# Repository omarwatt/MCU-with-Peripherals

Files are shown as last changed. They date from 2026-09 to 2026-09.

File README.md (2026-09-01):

# RISC-V MCU with Memory-Mapped Peripherals

## Project Overview

An FPGA microcontroller project integrating a 32-bit RISC-V-style processor with GPIO, a timer, UART, and interrupt handling. The work covers processor–peripheral integration, memory-mapped control, interrupt-driven firmware, simulation, and on-board verification using Signal Tap.

## Main Features

- Separate 8 KiB instruction and 8 KiB data memories.
- GPIO for eight switches, eight LEDs, and six seven-segment displays.
- Timer with selectable clock division, compare events, PWM, and edge capture.
- UART transmit/receive registers, status flags, and configurable parity and baud selection.
- Prioritized interrupts from UART, timer, and external keys.
- Hardware multiplication and a multicycle divider, with implementation restrictions described below.

## Architecture

`MCU.vhd` connects the processor, memories, address decoding, and peripherals. The processor uses a single-cycle datapath with multicycle sequences for division and interrupt entry. `MCU_top.vhd` provides the board-facing wrapper.

Interrupt handling uses custom vectors, an active-low acknowledge, `gp[0]` as a software interrupt-enable bit, and `tp` to hold the return address. This is a project-specific mechanism rather than the standard RISC-V privileged interrupt architecture.

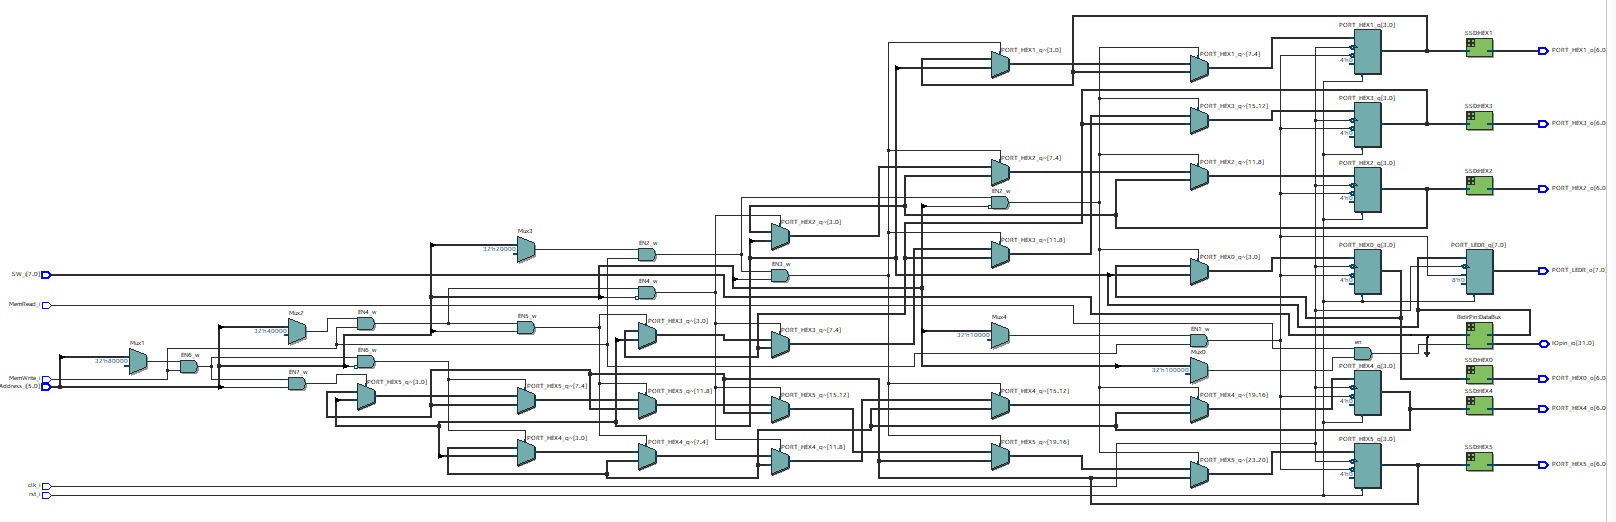
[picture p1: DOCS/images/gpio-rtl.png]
GPIO RTL structure

*Address decoding selects the GPIO registers and display outputs.*

## Tools and Technologies

VHDL, RISC-V assembly/C benchmarks, Intel Quartus Prime, ModelSim/Questa, Signal Tap Logic Analyzer, Intel `altsyncram` memories, and the DE10-Standard FPGA board.

## Simulation and Results

The archive contains block-level testbenches and an MCU testbench. UART and MCU tests include assertions; other tests also use directed stimulus and waveform inspection.

`DOC/pre.pdf` reports the following for the GPIO-and-interrupt configuration on Cyclone V `5CSXFC6D6F31C6`:

| Metric | Reported result |
| --- | ---: |
| ALMs | 2,017 |
| Registers | 1,743 |
| Memory bits | 131,072 |
| MCLK Fmax, slow 85°C corner | 29.09 MHz |

These are archived implementation results, not a newly reproduced build.

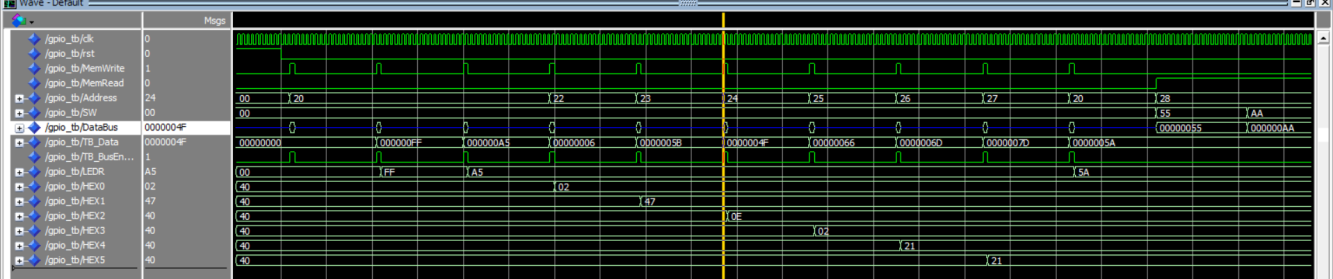
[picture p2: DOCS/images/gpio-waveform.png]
GPIO simulation

*MemWrite transactions update LEDR and HEX0–HEX5; MemRead returns switch patterns 0x55 and 0xAA on DataBus.*

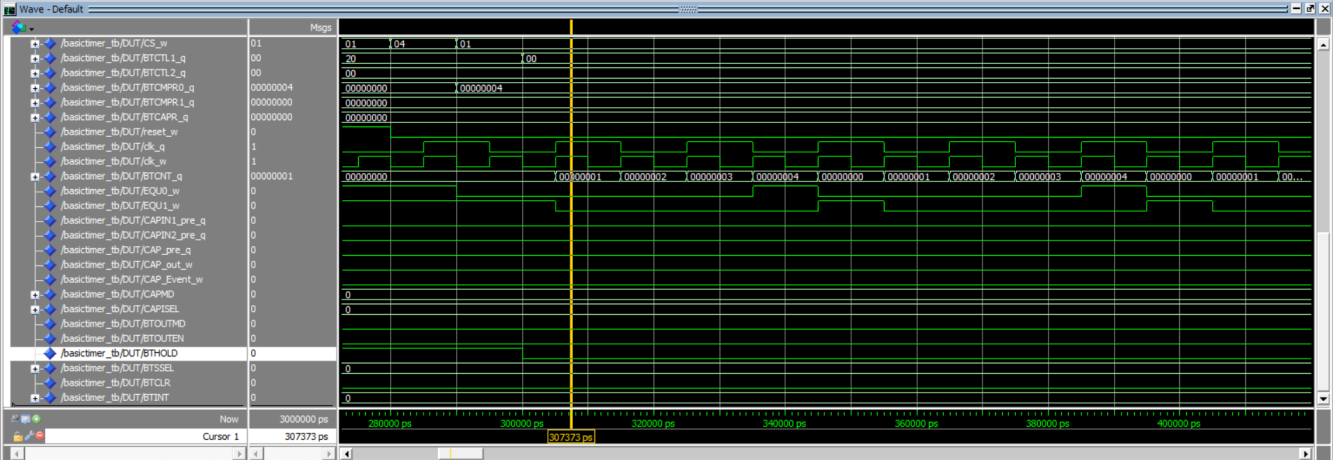
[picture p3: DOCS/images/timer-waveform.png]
Basic Timer simulation

*BTCNT_q counts to BTCMPR0 = 4 and reloads, while EQU0_w marks the compare event in this archived unit test.*

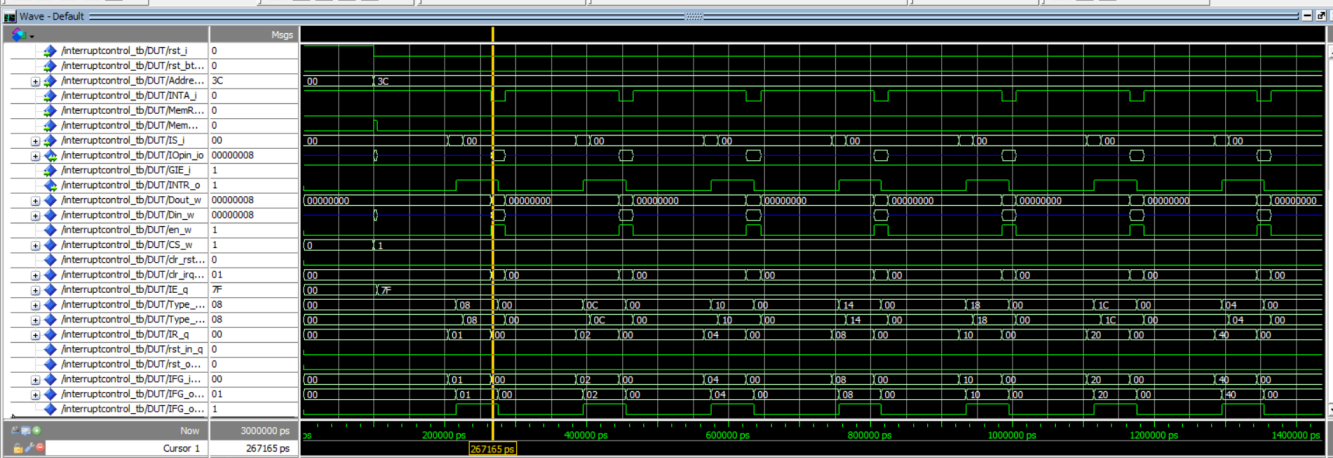
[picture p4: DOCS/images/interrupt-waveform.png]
Interrupt simulation

*IFG, TYPE, INTR, and active-low INTA show interrupt requests, vector selection, and acknowledgement.*

### On-Board Verification with Signal Tap

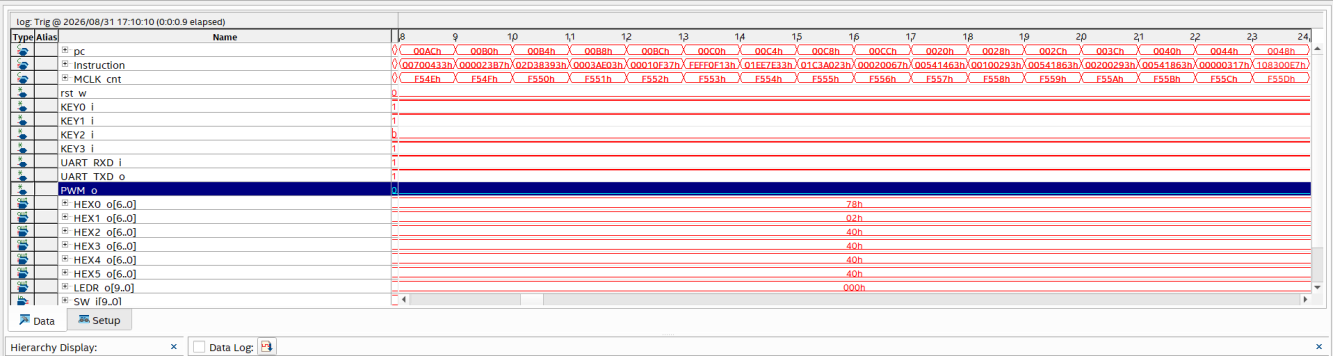
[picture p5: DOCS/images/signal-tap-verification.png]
On-board MCU Signal Tap capture

*The hardware capture shows the program counter, instruction words, advancing MCLK counter, and GPIO outputs during execution on the DE10-Standard board.*

The MCU was programmed onto the DE10-Standard board, and internal processor signals and peripheral outputs were captured using Signal Tap. The archived capture appears in `DOC/pre.pdf`, Figure 21 on page 14; `QUARTUS/stp1.stp` contains the Signal Tap session and recorded data.

- **Instruction execution:** the program counter advances through addresses including `0x00AC`–`0x00CC` and returns to the program loop, with instruction words captured alongside it.
- **Clock activity:** the MCLK counter advances from `0xF54E` to `0xF55D` in the displayed window, showing continued processor-clock activity.
- **Peripheral outputs:** `HEX0 = 0x78` and `HEX1 = 0x02` retain the programmed display values; `HEX2`–`HEX5` show `0x40`, and `LEDR` is zero. `PWM_o` is low and `UART_TXD` is high during this window.

The report compares the captured instruction flow and GPIO output states with the ModelSim benchmark run. This provides on-board evidence of processor execution and peripheral integration. The displayed idle UART and PWM levels do not independently verify serial transfers or PWM timing.

## Repository Structure

- `DUT/`: processor, peripherals, packages, memories, and board wrapper.
- `TB/`: block and MCU testbenches.
- `SIM/`: waveform configuration scripts.
- `Benchmark apps/`: example firmware and memory images.
- `QUARTUS/`: constraints, archived FPGA outputs, and the `stp1.stp` Signal Tap session.
- `DOC/`: project report.
- `docs/images/`: five selected design and results figures.

## How to Run

1. Configure a VHDL-2008 simulator with Intel's `altera_mf` simulation library.
2. Set `G_MODELSIM := 1` in `DUT/cond_compilation_package.vhd`.
3. Replace the absolute memory-image paths in `IFETCH.VHD` and `DMEMORY.VHD` with a matching instruction/data image pair.
4. Compile the packages, dependent DUT blocks, processor, MCU, and selected testbench in dependency order. Elaborate `tb_MCU` for system simulation.
5. Load the relevant waveform script under `SIM/` and run the testbench.

The waveform scripts do not compile the design. Match the MCU testbench's timer expectations to the selected firmware; its referenced fast-timer image is absent. Align the UART clock-frequency setting with the testbench clock before testing integrated serial communication.

To inspect the hardware verification, open `QUARTUS/stp1.stp` in Quartus Signal Tap and select the saved acquisition. For a new capture, connect the board through JTAG and use a matching FPGA programming file and Signal Tap configuration. Update the session's original absolute `.sof` path for your environment.

## Attribution

Course project by **Omar Wattad**, using the supplied course framework. The UART derives from **Jakub Cabal's uart-for-fpga**; retain its original copyright and MIT license notices alongside the course-code attribution.

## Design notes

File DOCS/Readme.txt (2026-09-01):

=====================================================================================================
FINAL PROJECT - RISCV-based MCU (Single-Cycle RV32IM Core + Memory-Mapped Peripherals + Interrupts)
Advanced CPU Architecture & Hardware Accelerators (361-1-4693) - Instructor: Hanan Ribo
Submitted by: Omar Wattad (207510819) , Fidaa Abo Aissa (324960996)
Target device: Intel Cyclone V  5CSXFC6D6F31C6  (DE10-Standard / DE-SoC board)
Tools: Quartus Prime 25.1std.0 | ModelSim | Signal-Tap | In-System Memory Content Editor (ISMCE) | RARS
=====================================================================================================

OVERVIEW
This project implements a complete RV32IM-based micro-controller (MCU) on an FPGA. The CPU is the
scalar single-cycle RV32IM core developed in LAB5, extended into a micro-controller by adding a
memory-mapped peripheral subsystem, an interrupt mechanism, a UART serial interface and a multicycle
unsigned division accelerator running in its own fast clock domain.

The design keeps the Harvard organisation of the core - separate ITCM (instruction) and DTCM (data)
tightly-coupled memories of 8 kB each. All peripherals are mapped into the Data Address Space above
the physical data memory (byte address 0x2000 and up) and share one bidirectional 32-bit Data BUS, so
the CPU accesses them with ordinary lw / sw instructions. The top level and the RV32IM core are both
structural. Push-button KEY0 is the system RESET (brings the PC to the first program instruction).

-----------------------------------------------------------------------------------------------------
CLOCKING
-----------------------------------------------------------------------------------------------------
baseclk 50 MHz -> Clock Tree / PLLs:
  MCLK    - core clock. Clocks the CPU, the bus, all peripherals and the MCLK counter.
  DIVCLK  - fast clock. Clocks the division accelerator only (32 DIVCLK cycles per 32-bit division).
  SMCLK   - peripheral clock source feeding the Basic Timer pre-scaler and the UART baud generator.
The MCLK and DIVCLK domains meet only through the Sync (CDC) block, so no combinational signal crosses
a clock boundary unregistered.

-----------------------------------------------------------------------------------------------------
CPU CORE SUB-MODULES  (RV32IM_CORE, structural)
-----------------------------------------------------------------------------------------------------

IFETCH (Ifetch:IFE)
Instruction-fetch stage. Holds the PC register and the PC+4 adder, contains the ITCM (8 kB, FPGA
embedded altsyncram), and selects the next PC through a mux choosing between PC+4, a branch/jump
target and - during an interrupt - the vector address supplied by the ISR sequence. Outputs the
fetched instruction and the current PC.

IDECODE (Idecode:ID)
Decode stage. Contains the RISC-V register file (32 x 32-bit, two read ports, one write port) and the
sign-extension / immediate-generation logic for I/S/B/U/J formats. Supplies read_data1 and read_data2
to EXECUTE and routes the write-back value into the destination register rd.

CONTROL (control:CTL)
Main control unit. Decodes opcode and funct fields into the datapath control signals: ALUOp, ALUSrc,
MULOp, DIVOp, Branch, Jal, Jalr, MemRead, MemWrite, MemtoReg, RegDst, RegWrite, UpperIm and WBSrc.
It also contains the multicycle ISR FSM (see "Interrupt service protocol" below) and handles PChold /
DIVbusy stalling while the division accelerator is busy.

EXECUTE (Execute:EXE)
Execute stage. Contains the ALU (add/sub, logic, shift, signed and unsigned comparison for branch
resolution), the 16-bit multiplier, branch-target / effective-address generation, and the result mux
that selects the value forwarded to memory / write-back (ALU result, multiplier result, divider
quotient/residue, memory data, PC+4 or the upper immediate).

16-BIT MULTIPLIER (mul)
Implements the mul instruction of the M-extension. mul rd, rs1, rs2 multiplies the lower 16-bit
half-words of rs1 and rs2 into a 32-bit product, built from four embedded 8-bit multipliers (DSP):
   P0 = A_low x B_low , P1 = A_low x B_high , P2 = A_high x B_low , P3 = A_high x B_high
   M  = P1 + P2 ,   RESULT = P0 + (M << 8) + (P3 << 16)
Purely combinational in the single-cycle core.

DMEMORY (dmemory:MEM)
Data-memory stage. Contains the DTCM (8 kB, FPGA embedded altsyncram) with the load/store interface,
clocked on not(clk) so a load can be fetched, decoded, address-computed and read in the same period.
It also hosts the bus interface logic: the address decoder that separates DTCM accesses from I/O
accesses, and the merge of the peripheral read data back onto the Data BUS.

MCLK COUNTER
A free-running cycle counter clocked by MCLK, cleared on reset; drives mclk_cnt_o.

-----------------------------------------------------------------------------------------------------
PERIPHERAL SUB-MODULES
-----------------------------------------------------------------------------------------------------

GPIO (GPIO_UNIT)
Eight memory-mapped GPIO peripherals: an optimized address decoder generates the chip-selects CS1..CSn
from Address<A4..A0>, MemWrite latches the Data BUS into the addressed port register, and MemRead with
the matching CS enables a tri-state driver (BidirPinDataBus) that returns the register onto the bus.
Each HEX port register passes through a 7-segment encoder (SSD.vhd) before leaving the block.
   PORT_LEDR 0x2000 (LEDR7-LEDR0, GPO)      PORT_HEX3 0x2009 (GPO)
   PORT_HEX0 0x2004 (GPO)                   PORT_HEX4 0x200C (GPO)
   PORT_HEX1 0x2005 (GPO)                   PORT_HEX5 0x200D (GPO)
   PORT_HEX2 0x2008 (GPO)                   PORT_SW   0x2010 (SW7-SW0, GPI)

PUSHBUTTONS (Pushbuttons / uart_debouncer)
PORT_PB (0x2014) exposes the three debounced pushbuttons KEY3-KEY1 as an input device. Each key is
debounced and edge-detected; the resulting pulse is an interrupt source (KEY1IFG / KEY2IFG / KEY3IFG)
towards the interrupt controller. KEY0 is NOT a peripheral - it is the system reset.

BASIC TIMER (BasicTimer)
32-bit up-mode timer with compare, PWM output and input capture.
   BTCTL1  0x201C  BTOUTMD | BTOUTEN | BTHOLD | BTSSEL | BTCLR | BTINT
   BTCTL2  0x201D  CAPMD | CAPISEL
   BTCMPR0 0x2020  compare/PWM value 0   (latched into BTCL0)
   BTCMPR1 0x2024  compare/PWM value 1   (latched into BTCL1)
   BTCAPR  0x2028  capture register
BTSSEL selects the counter clock from {SMCLK, SMCLK/2, SMCLK/4, SMCLK/8}. BTCNT counts up and is
cleared when it equals BTCL0, producing the periodic BTIFG interrupt (source selected by BTINT).
The Output Unit generates PWM_out in Output Mode0 (Set/Reset) or Mode1 (Reset/Set) from the BTCL0 /
BTCL1 comparisons. The capture path selects CAPIN1, CAPIN2, VCC or GND (CAPISEL), detects a rising or
falling edge (CAPMD) and latches BTCNT into BTCAPR on the event.

DIVISION ACCELERATOR (DIV + Sync)
Unsigned binary multicycle restoring divider, 32-bit. The dividend is held in a left-shift register,
the divisor in a register; each DIVCLK cycle the subtractor computes Y-X and a non-negative result
shifts a '1' into the quotient shift-register. Results (QUOTIENT, RESIDUE) are ready N=32 DIVCLK
cycles after the second operand is loaded; DIVBUSY stalls the CPU (PChold) meanwhile. Operands cross
from MCLK into DIVCLK through Sync.vhd - two cascaded DFF stages per operand (Ain, Bin) clocked by
DIVCLK, as required for a slow-to-fast clock-domain crossing, so no metastable value reaches the
divider datapath.

UART (uart, uart_tx, uart_rx, uart_parity, uart_debouncer)
USART peripheral in UART mode: 1 start bit, 8 data bits LSB-first, optional parity, 1 stop bit, with
independent transmit and receive shift registers and separate buffer registers.
   UCTL  0x2018  BUSY | OE | PE | FE | BAUDRATE | PEV | PENA | SWRST
   RXBF  0x2019  receive buffer  (reading it clears the receive error bits and RXIFG)
   TXBF  0x201A  transmit buffer (writing it clears TXIFG)
The baud-rate generator divides SMCLK to 9600 or 115200 (BAUDRATE bit). Status flags FE (framing),
PE (parity) and OE (overrun) are set by the receive control logic. RX and TX are independent
interrupt sources (RXIFG, TXIFG).

INTERRUPT CONTROLLER (InterruptControl)
   IE   0x202C  0 | 0 | KEY3IE  | KEY2IE  | KEY1IE  | BTIE  | TXIE  | RXIE
   IFG  0x202D  0 | 0 | KEY3IFG | KEY2IFG | KEY1IFG | BTIFG | TXIFG | RXIFG
   TYPE 0x202E  interrupt vector of the served source (read-only)
Each source drives a set-only flag flip-flop (clr_irq clears it). The flag is ANDed with its enable
bit, all masked requests are OR-ed together and gated by GIE to produce INTR towards the CPU. On INTA
the controller resolves the highest-priority pending source and drives its vector onto TYPE:
   00h RESET (NMI, highest) | 04h UART status error | 08h UART RX | 0Ch UART TX
   10h Basic Timer | 14h KEY1 | 18h KEY2 | 1Ch KEY3 (lowest)
BTIFG, RXIFG and TXIFG are cleared automatically when serviced (RXIFG also on RXBF read, TXIFG also on
TXBF write); the KEYiIFG flags are cleared by software.

SSD (SSD.vhd)
Combinational 4-bit-to-7-segment encoder instantiated once per HEX port inside the GPIO block.

-----------------------------------------------------------------------------------------------------
INTERRUPT SERVICE PROTOCOL (multicycle FSM inside CONTROL)
-----------------------------------------------------------------------------------------------------
The FSM is triggered by the falling edge of INTA, the cycle after the controller sets INTR = '1'. The
next PC at that moment is the interrupt return address.
Servicing (2-cycle latency):
  Cycle 1 : clear GIE (gp[0] = 0) in HW ; set INTA = '1' ; drive the TYPE content onto the Data BUS
            and capture it into a dedicated register (TYPE cannot go on the Address BUS - the CPU is
            the only bus master).
  Cycle 2 : if the pending source is synchronous, clear its flag (e.g. BTIFG) ; emulate load of the
            TYPE content followed by jalr to Mem[TYPE], with R[tp] = interrupt return address.
Return (1-cycle latency):
  As part of executing "jalr zero, 0(tp)" (reti), GIE is set again in HW.

-----------------------------------------------------------------------------------------------------
SYSTEM TOP ENTITY  (MCU_top.vhd, structural)
-----------------------------------------------------------------------------------------------------
Inputs : clk_i (50 MHz -> PLLs), KEY0 (system reset), KEY3-KEY1 (pushbutton peripheral / interrupts),
         SW9-SW0, CAPIN1, CAPIN2, UART_RXD
Outputs: LEDR9-LEDR0, HEX5-HEX0, PWM_o, UART_TXD
Submodules: RV32IM_CORE (CPU) , GPIO_UNIT , TIMER_UNIT , IC_UNIT , UART_UNIT , DIV + Sync ,
            PLL \G0:MCLK , PLL \G0:DIVCLK , MCLK counter.
Observation ports (Signal-Tap, removed from the final build through the generate parameter):
PC_o, Instruction_o, INTA_o, GIE_o, INTR_o, MemRead_ctrl_o, MemWrite_ctrl_o, RegWrite_ctrl_o,
alu_res_o, dtcm_addr_o, dtcm_data_wr_o, dtcm_data_rd_o, mclk_cnt_o.

-----------------------------------------------------------------------------------------------------
FPGA I/O INTERFACE  (Cyclone V 5CSXFC6D6F31C6, DE10-Standard)
-----------------------------------------------------------------------------------------------------
  CLK 50 MHz - board oscillator, feeds the PLLs that generate MCLK / DIVCLK / SMCLK.
  KEY0       - system RESET (brings the PC to the first program instruction).
  KEY3-KEY1  - debounced pushbutton peripheral PORT_PB and interrupt sources.
  SW9-SW0    - PORT_SW input peripheral (SW7-SW0 readable by the CPU).
  LEDR9-LEDR0- PORT_LEDR output peripheral.
  HEX5-HEX0  - six 7-segment displays driven by PORT_HEX5..PORT_HEX0 through the SSD encoders.
  PWM_o      - Basic Timer PWM output.
  UART_TXD / UART_RXD - RS-232 link to the PC through the USB-to-serial (FTDI) bridge.
Only the MCU I/O devices are assigned in the Pin Planner; the Signal-Tap observation pins are removed
in the final compilation.

Data flow summary
  switches / keys / UART_RXD -> peripheral registers -> Data BUS -> RV32IM core (fetch -> decode ->
  execute / multiply / divide -> data memory -> write-back) -> Data BUS -> peripheral registers ->
  LEDR / HEX / PWM / UART_TXD , with INTR / INTA closing the interrupt loop between IC_UNIT and CPU.

-----------------------------------------------------------------------------------------------------
VERIFICATION FLOW
-----------------------------------------------------------------------------------------------------
1. Unit level - each peripheral is driven by its own test bench over the memory-mapped interface:
   gpio_tb , basictimer_tb , interruptcontrol_tb , uart_tb , div_tb.
2. System level - tb_mcu runs the benchmark applications test1..test4 out of the ITCM while the CPU
   and every peripheral instance are observed simultaneously.
3. Golden model - at the end of each run the ModelSim DTCM.mem output is compared against the RARS
   DTCM.hex golden file; on the board the ISMCE DTCM.hex read-back is compared against the same file.
4. On-board - Signal-Tap captures the observation ports live; ISMCE inspects ITCM and DTCM contents.

-----------------------------------------------------------------------------------------------------
PPA SUMMARY (Quartus Prime 25.1std.0, Cyclone V 5CSXFC6D6F31C6, Slow 1100 mV 85 C)
-----------------------------------------------------------------------------------------------------
  MCU with GPIO                    : 1,886 ALMs , 1,701 registers , 4 DSP , 2 PLLs , 131,072 mem bits
                                     Fmax(MCLK) = 28.72 MHz , total power 453.88 mW
  MCU with GPIO + Interrupt (+UART, +DIV)
                                   : 2,025 ALMs , 1,741 registers , 4 DSP , 3 PLLs , 131,072 mem bits
                                     Fmax(MCLK) = 28.46 MHz , DIVCLK = 144.97 MHz , total 455.06 mW
  f_MCLK = f_sysclk <= Fmax in every configuration. Full tables and report screenshots are in
  DOC/Final_report.pdf.

-----------------------------------------------------------------------------------------------------
SUBMISSION DIRECTORY STRUCTURE
-----------------------------------------------------------------------------------------------------
DUT/RV32IMscMCU         - design VHDL files only (no test benches):
                          MCU_top.vhd, RV32IM_CORE.vhd, Ifetch.vhd, Idecode.vhd, CONTROL.vhd,
                          Execute.vhd, dmemory.vhd, GPIO.vhd, SSD.vhd, Pushbuttons.vhd,
                          BasicTimer.vhd, InterruptControl.vhd, DIV.vhd, Sync.vhd, uart.vhd,
                          uart_tx.vhd, uart_rx.vhd, uart_parity.vhd, uart_debouncer.vhd, PLL_SM.vhd
DUT/RV32IMpipelinedMCU  - (bonus) pipelined variant of the same design
TB/RV32IMscMCU          - tb_RV32IMscMCU.vhd
TB/RV32IMpipelinedMCU   - (bonus) tb_RV32IMpipelinedMCU.vhd
SIM/RV32IMscMCU         - ModelSim *.do script
SIM/RV32IMpipelinedMCU  - (bonus) ModelSim *.do script
DOC                     - this Readme.txt and Final_report.pdf
Quartus/RV32IMscMCU     - Signal-Tap file, SDC file, SOF file
Quartus/RV32IMpipelinedMCU - Signal-Tap file, SDC file, SOF file

Both the ModelSim and the Quartus projects compile without errors.
=====================================================================================================

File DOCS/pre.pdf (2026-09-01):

Final Project — Structural RV32IM MCU

Advanced CPU Architecture · Hanan Ribo · BGU | Page 1

## Ben-Gurion University of the Negev

Electrical & Computer Engineering

Advanced CPU Architecture & Hardware Accelerators — Course 361-1-4693

# FINAL PROJECT REPORT

## Structural RV32IM Micro-Controller Unit (MCU)

GPIO · Basic Timer · Interrupt Controller · UART · Restoring-Divider Accelerator

Intel Cyclone V — DE10-Standard (5CSXFC6D6F31C6)

Submitted by:
Omar Wattad — ID 207510819

Fidaa Abo Aissa — ID 324960996

Instructor: Hanan Ribo
August 2026

## Table of Contents

## 1. Aim and Assignment Definition

This report documents the design, synthesis, implementation and functional verification of a complete RV32IM micro-controller unit (MCU) on an Intel Cyclone V FPGA. The MCU is built around the scalar single-cycle RV32IM core developed in LAB5 and extends it into a full micro-controller by adding a memory-mapped peripheral subsystem and an interrupt mechanism.

The design is delivered in incremental configurations, each of which is characterised independently for Power, Performance and Area (PPA):

- MCU with GPIO — the RV32IM core plus the memory-mapped GPIO block (switches SW, LEDs LEDR, six seven-segment displays HEX0–HEX5) and the Basic Timer, connected over the shared data bus.
- MCU with GPIO and Interrupt Capability — the above plus the Interrupt Controller (IE / IFG / IR / Type registers, GIE, INTA hand-shake and vector generation), the UART transceiver and the restoring-divider hardware accelerator with its clock-domain-crossing wrapper.
- Pipelined MCU with GPIO and Interrupt Capability — the same peripheral subsystem attached to the 5-stage pipelined RV32IM core of LAB5 Part 2.
All blocks are described in structural/behavioural VHDL and instantiated in a structural top level (MCU_top.vhd). The system keeps the Harvard organisation of the core — separate ITCM and DTCM tightly-coupled memories of 8 kB each — while all peripherals are mapped into the DTCM address space and share the bidirectional 32-bit DataBus. A PLL derives the CPU clock MCLK from the 50 MHz board clock; a second PLL output (DIVCLK) drives the divider accelerator in its own faster clock domain.

### 1.1 Memory-mapped peripheral interface

Every peripheral follows the same bus protocol: an address decoder produces a chip-select (CS_w), MemWrite_i latches the bus into the addressed register, and MemRead_i together with CS_w enables a tri-state driver (BidirPinDataBus) that returns the selected register onto DataBus. Because only one enable can be active at a time, the peripherals arbitrate the shared bus without any additional glue logic. The CPU therefore accesses the timer, GPIO, interrupt controller, UART and divider with ordinary lw/sw instructions.

### 1.2 Interrupt mechanism

Interrupt sources (the timer BTIFG, the GPIO push-buttons KEY1–KEY3 and the UART) are captured in the IFG register, masked by IE and by the global GIE bit, and combined into a single INTR request towards the core. The core answers with INTA; the controller then places the corresponding vector taken from the Type register onto the bus, and the ISR FSM inside CONTROL.VHD redirects the PC to the service routine and back. KEY0 is reserved as the asynchronous system reset.

## 2. RTL Viewer Results

The Quartus RTL Viewer confirms the structural hierarchy of each block. The figures below show the elaborated netlists of the four main peripherals; in each of them the address-decode multiplexer chain is visible on the left, the memory-mapped register bank in the middle, and the read-back multiplexer with the tri-state bus driver (BidirPinDataBus) on the right.

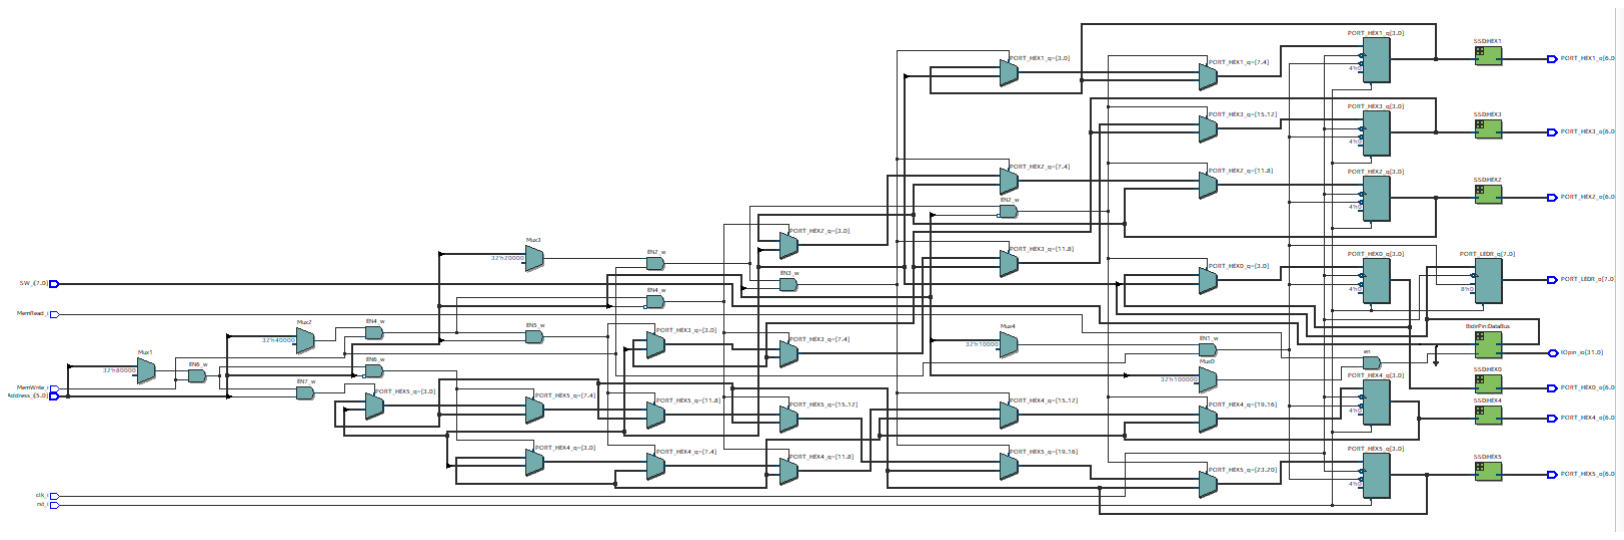
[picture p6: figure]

Figure 1: GPIO — RTL Viewer. Address decoding (Mux0–Mux4) drives the enable signals EN1_w–EN7_w of the LEDR/HEX0–HEX5 port registers; each HEX register feeds an SSD decoder before leaving the block.

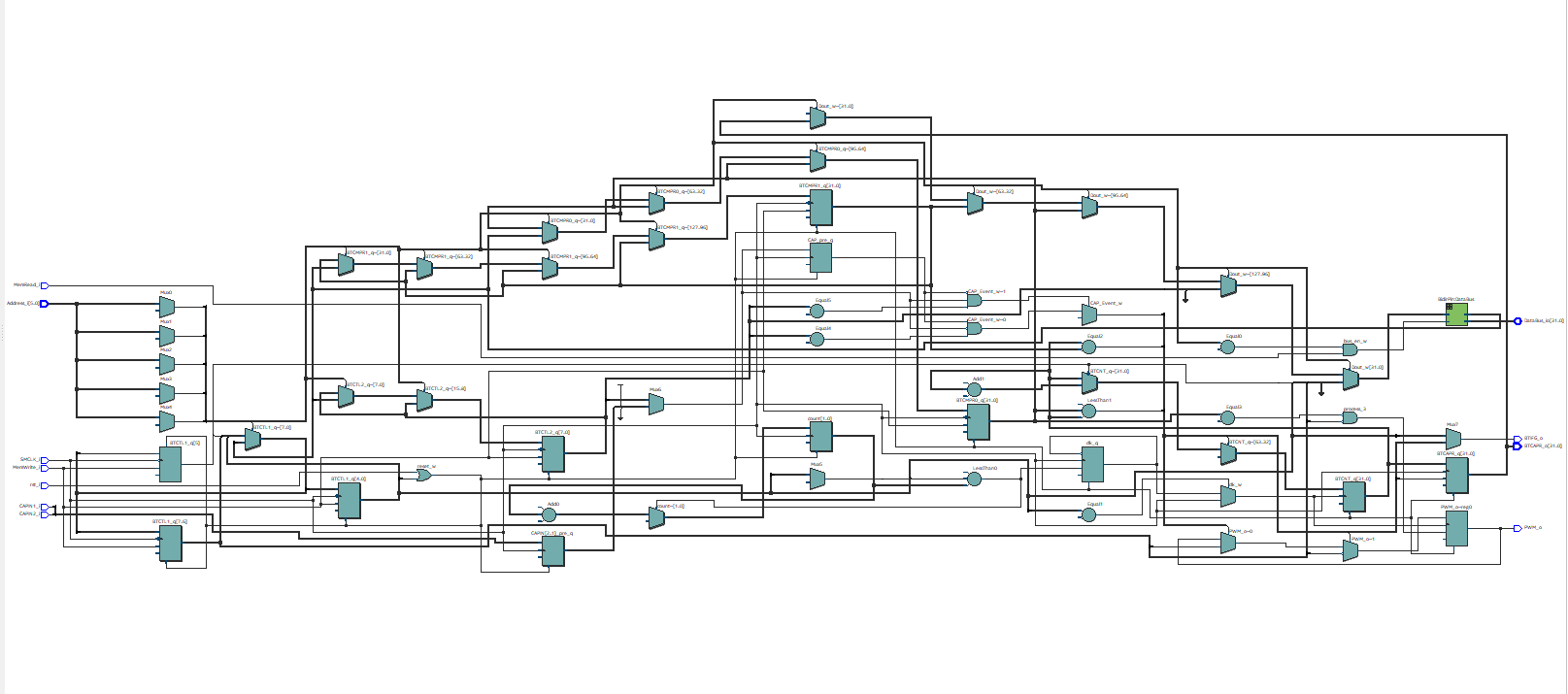
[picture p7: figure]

Figure 2: Basic Timer — RTL Viewer. BTCTL1/BTCTL2, BTCMPR0/BTCMPR1 and BTCAPR registers, the clock-divider chain (clk_q / clk_w), the BTCNT up-counter with its EQU0/EQU1 comparators, the capture logic (CAP_pre_q, CAP_Event_w) and the PWM output generator.

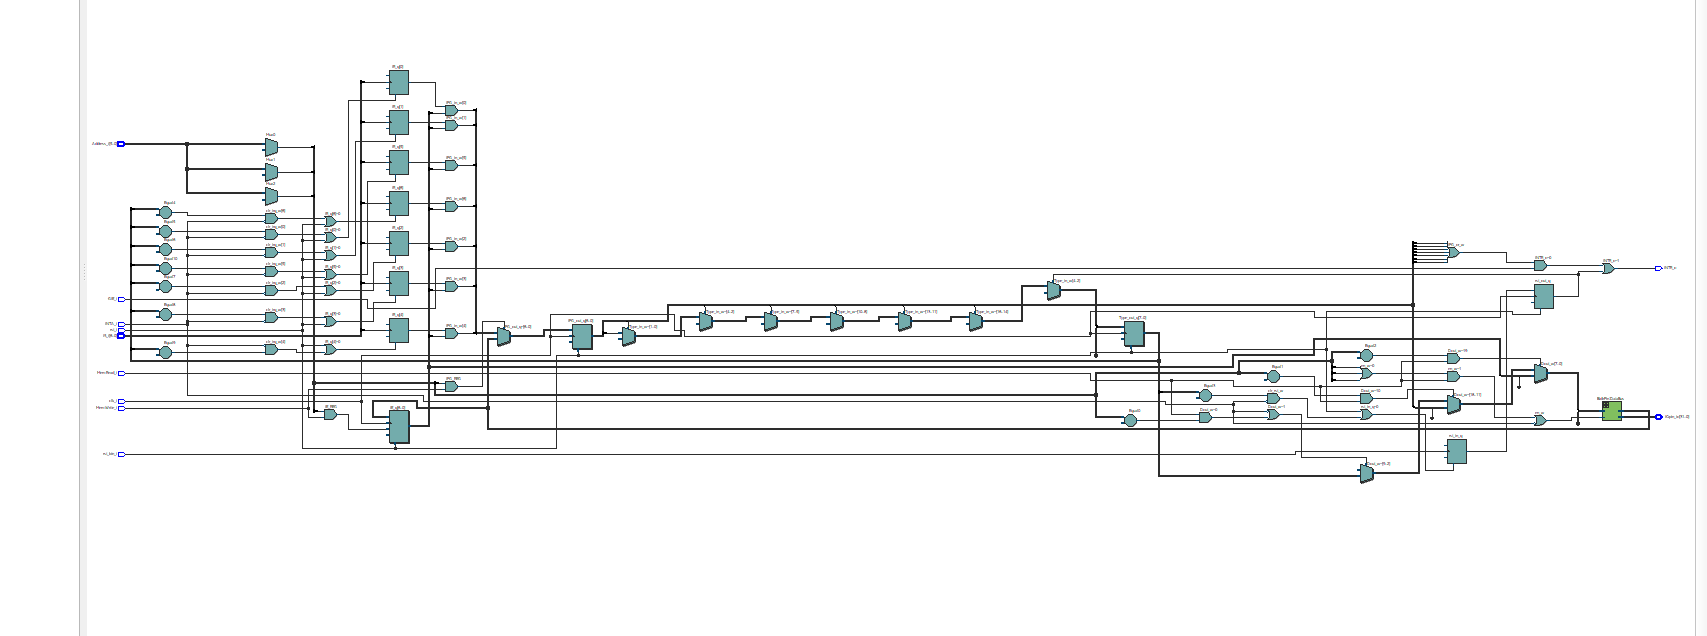
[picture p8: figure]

Figure 3: Interrupt Controller — RTL Viewer. The IE / IFG / IR / Type register bank on the left, the priority-encoded vector generation and the Type_out pipeline in the middle, and the INTR output logic plus the bus read-back path on the right.

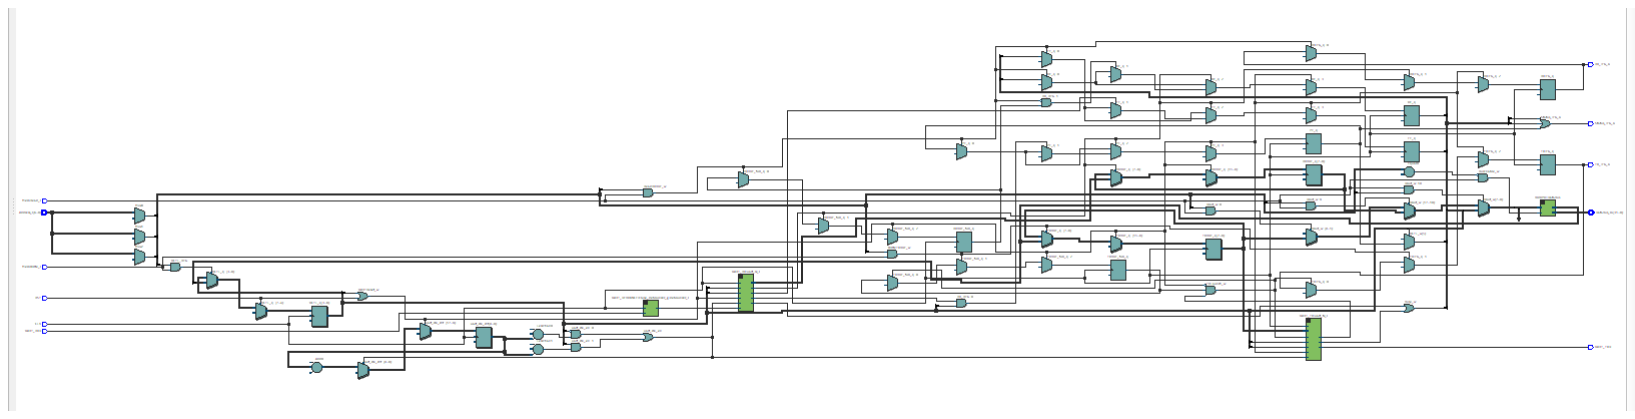
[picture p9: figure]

Figure 4: UART — RTL Viewer. Transmit and receive shift registers with their baud-rate counters, parity generation/checking and the status/control registers exposed on the peripheral bus.

## 3. PPA Characterization

All figures below are taken from Quartus Prime 25.1std.0 compilations targeting the Cyclone V 5CSXFC6D6F31C6 device (Timing Models: Final). On Cyclone V the area metric is Adaptive Logic Modules (ALMs) rather than Cyclone-IV logic elements, and the embedded 9-bit multipliers are realised inside variable-precision DSP blocks.

### 3.1 Area

Configuration

Logic
elements
(ALMs)
| | Registers | I/O
| | | pins | Embedded
| | | | memory bits | Embedded 9-
| | | | | bit
| | | | | multipliers | PLLs
MCU with GPIO | 1,903 | 1,703 | 70 | 131,072 | 4 | 2

MCU with GPIO and
Interrupt Capability | 2,017 | 1,743 | 70 | 131,072 | 4 | 2

Pipelined MCU with
GPIO and Interrupt Capability | — | — | — | — | — | —

Table 1: Area characterization (Quartus Analysis & Synthesis Resource Usage Summary). Combinational ALUT usage is 2,481 and 2,615 respectively.

Adding the interrupt capability, the UART and the divider accelerator costs +114 ALMs (+6.0 %), +134 combinational ALUTs and +40 dedicated registers — a small increment, because the added logic is dominated by narrow control registers (IE, IFG, IR, Type) and by FSM state rather than by datapath width. The I/O pin count is unchanged at 70, and the block-memory, DSP and PLL usage are identical in both configurations, because the ITCM/DTCM sizes, the 16-bit multiplier and the two clock domains (MCLK and DIVCLK) are common to both builds.

The maximum fan-out node differs between the two builds: in the GPIO configuration it is the global reset rst_w with 1,474 loads, while in the full configuration it becomes the MCLK net with 1,386 loads. Both are expected for a design in which every architectural register is clocked from one net and cleared from another; the average fan-out is essentially constant (4.71 versus 4.72).

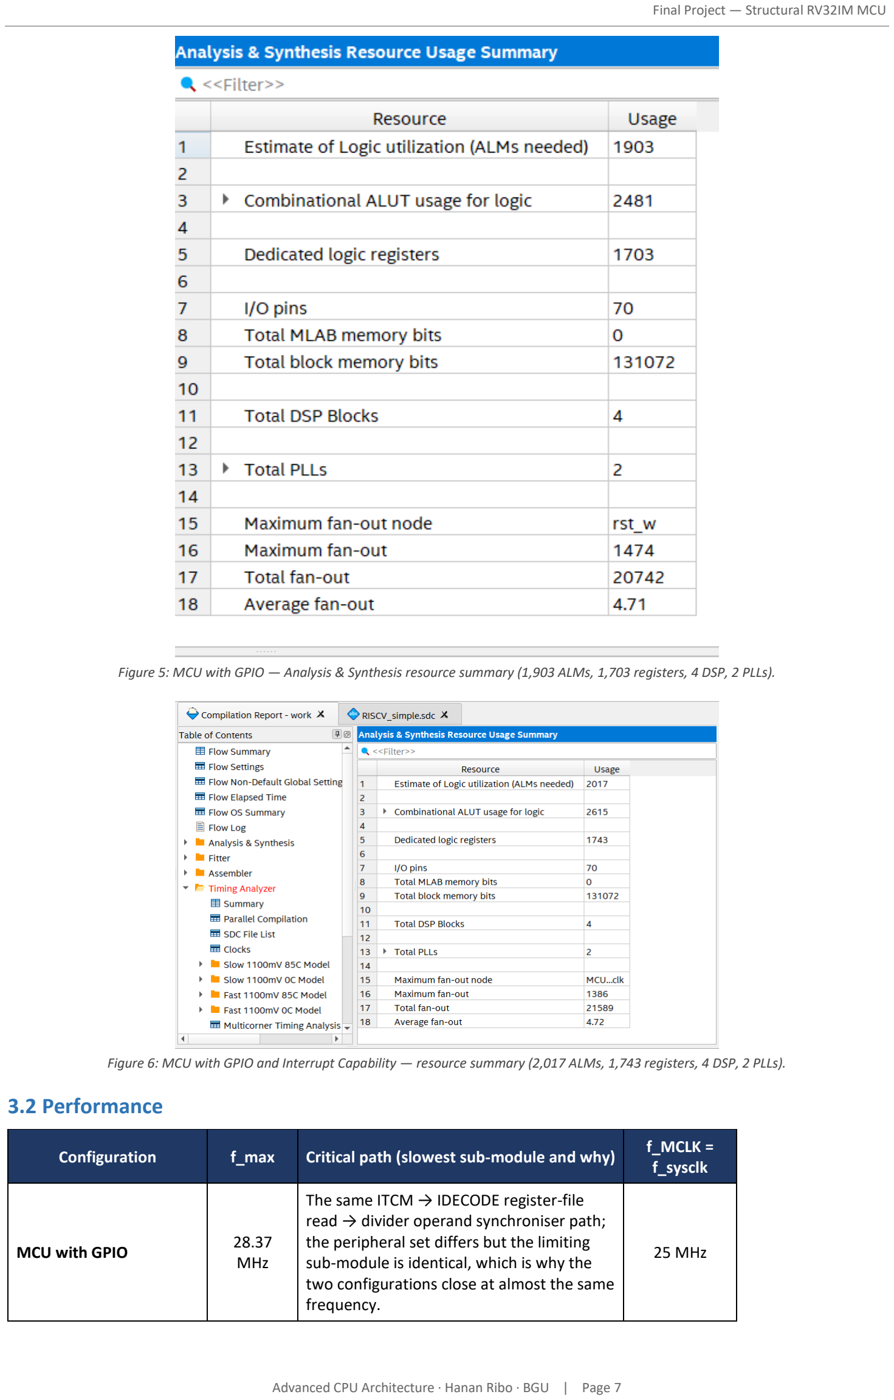
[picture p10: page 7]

Figure 5: MCU with GPIO — Analysis & Synthesis resource summary (1,903 ALMs, 1,703 registers, 4 DSP, 2 PLLs).

Figure 6: MCU with GPIO and Interrupt Capability — resource summary (2,017 ALMs, 1,743 registers, 4 DSP, 2 PLLs).

### 3.2 Performance

Configuration | f_max | Critical path (slowest sub-module and why) | f_MCLK = f_sysclk
MCU with GPIO | 28.37 MHz

The same ITCM → IDECODE register-file read → divider operand synchroniser path; the peripheral set differs but the limiting sub-module is identical, which is why the two configurations close at almost the same frequency.

25 MHz

Configuration | f_max | Critical path (slowest sub-module and why) | f_MCLK = f_sysclk

MCU with GPIO and
Interrupt Capability

29.09
MHz

ITCM (altsyncram) instruction output → instruction-bit decode
(Instruction_ID_w[22]~3) → the IDECODE register-file read multiplexer chain (Mux48~2 → Mux48~4 → Mux48~10) → the divider operand register Bin_q[15] inside Sync:Synchronizer. The slowest sub-module is IDECODE: the fetched instruction must select a register-file source through three cascaded 48-input multiplexers and the read data must still reach the CDC input register of the division accelerator within one MCLK period. Interconnect dominates (IC 1.624 ns on Mux48~2, 0.906 ns on Bin_q[15]) rather than cell delay.

25 MHz

Pipelined MCU with GPIO
and Interrupt Capability | —

Expected to migrate to the IDECODE register-file write path, as measured in LAB5.

—

Table 2: Performance characterization (Slow 1100 mV 85 °C model). f_MCLK is the frequency actually programmed into the PLL and used by the system; it is set to 25 MHz, safely below the Fmax of both implemented configurations.

The Fmax report lists four clocks. MCLK — the PLL output that clocks the CPU and the peripherals — closes at 29.09 MHz and is therefore the system limit: f_MCLK = f_sysclk ≤ 29.09 MHz. DIVCLK, the separate PLL output feeding the divider accelerator, closes at 139.55 MHz, so the accelerator is roughly 4.8 times clear of the bottleneck and the CDC wrapper correctly isolates the two domains. The 1,121.08 MHz figure reported on clk is the raw 50 MHz input port before the PLL and covers only the trivial input-to-PLL path, restricted to 717.36 MHz by the device minimum period, while altera_reserved_tck (94.15 MHz) belongs to the JTAG / Signal-Tap infrastructure and is not part of the user design.

Compared with the 34.99 MHz achieved by the bare single-cycle core in LAB5, the MCU loses roughly 17 % of its clock frequency. The technology-map view of the worst-case path shows where it went: the path starts at the ITCM output, passes through the instruction-bit decode into the IDECODE register-file read multiplexer chain, and ends at the operand register Bin_q[15] of the divider synchroniser. In the bare core the register-file read fed only the ALU; in the MCU the same read data must additionally reach the CDC input register of the division accelerator in the same cycle, which lengthens the fan-out and the routing of that net. Interconnect, not cell delay, dominates every hop of the path.

Between the two MCU configurations the difference is small: 28.37 MHz with GPIO alone against 29.09 MHz with the full peripheral set, i.e. 2.5 % in favour of the larger design. Since additional logic cannot physically shorten a critical path, this inversion is placement-and-routing variation between two independent fitter runs rather than an architectural effect. The correct reading is that the interrupt controller, the UART and the divider are effectively free in clock frequency: they add sources to the bus read-back multiplexer and insert the Type/vector multiplexer, but the limiting path is the same ITCM → register-file read → divider-synchroniser path in both builds. The DIVCLK domain closes at a similar value in both compilations (143.12 MHz and 139.55 MHz), confirming that the accelerator is never the bottleneck.

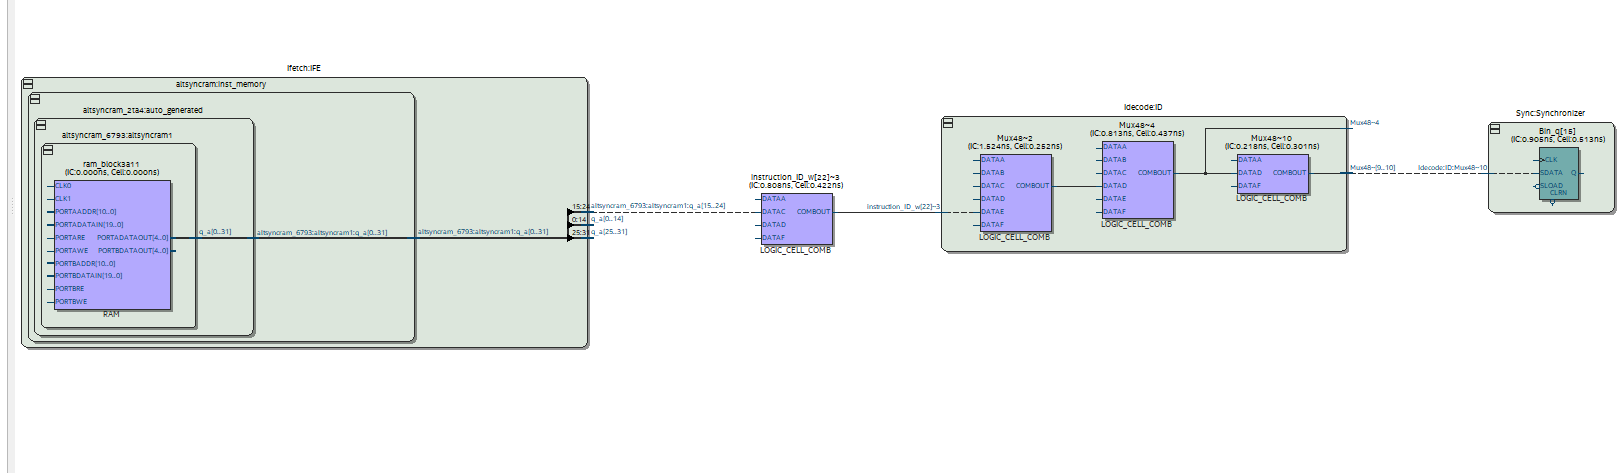
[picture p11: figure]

Figure 7: Critical-path technology map. ITCM (altsyncram) → Instruction_ID_w[22]~3 → the IDECODE multiplexer chain Mux48~2 / Mux48~4 / Mux48~10 → Bin_q[15] in Sync:Synchronizer. Per-hop delays are annotated as IC (interconnect) / Cell.

The system is clocked well inside this limit: the PLL is programmed to produce f_MCLK = f_sysclk = 25 MHz, which leaves roughly 13 % margin over the worst-case 28.37 MHz corner and keeps the design robust across the slow and fast timing models.

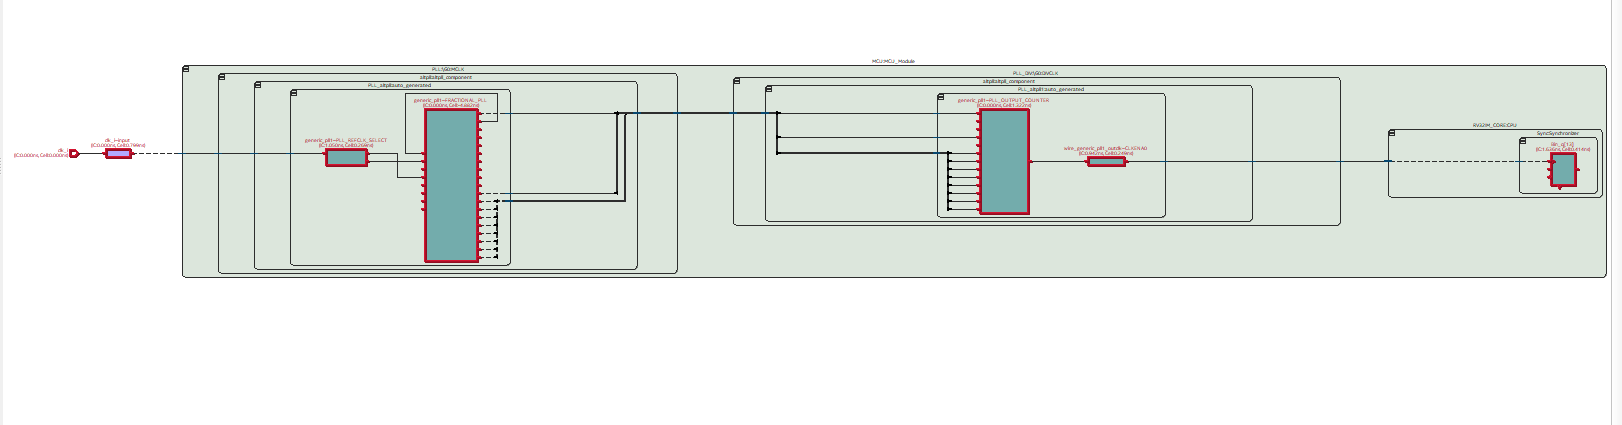
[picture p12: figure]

Figure 8: Technology-map view of the clock-generation network. The 50 MHz board clock clk_i enters the fractional PLL PLL:\G0:MCLK, whose output counter produces MCLK; the second PLL PLL:\G0:DIVCLK produces the divider-accelerator clock, which re-enters the core through the SyncSynchronizer instance inside RV32IM_CORE:CPU. This confirms that the two clock domains are physically separated and crossed only through the synchroniser.

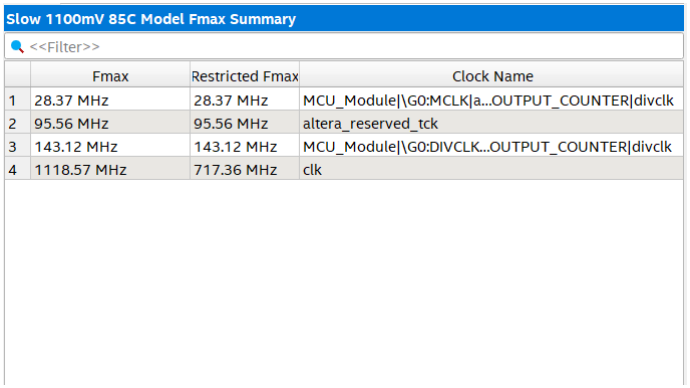
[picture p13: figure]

Figure 9: MCU with GPIO — Slow 1100 mV 85 °C Fmax summary. MCLK = 28.37 MHz (system limit); DIVCLK = 143.12 MHz.

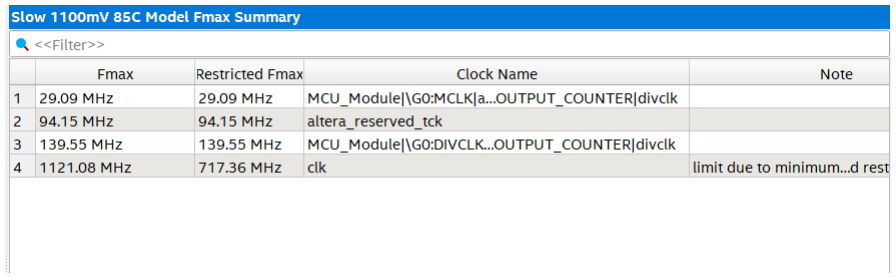
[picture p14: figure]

Figure 10: MCU with GPIO and Interrupt Capability — Slow 1100 mV 85 °C Fmax summary. MCLK = 29.09 MHz (system limit); DIVCLK = 139.55 MHz.

### 3.3 Power

Configuration | Total power | Static power | Dynamic
| | | power | I/O power
MCU with GPIO | 453.88 mW | 415.34 mW | 25.14 mW | 13.40 mW

MCU with GPIO and
Interrupt Capability | 455.09 mW | 415.35 mW | 26.36 mW | 13.39 mW

Pipelined MCU with GPIO
and Interrupt Capability | — | — | — | —

Table 3: Power characterization (PowerPlay, Final timing models). Estimation confidence is Low because the .vcd toggle data is partial, so the absolute numbers are indicative and only the relative comparison is meaningful.

Static power (≈ 415.3 mW) is identical in both configurations, as expected: it depends on the device, the process corner and the junction temperature, not on the utilised logic. The whole difference therefore appears in the dynamic term, which grows from 25.14 mW to 26.36 mW (+4.9 %) — consistent with the +40 registers and +114 ALMs that toggle every MCLK edge. I/O power is flat (13.40 → 13.39 mW) because the pin count is unchanged at 70 and the added peripherals drive internal nodes rather than new pins.

Figure 11: MCU with GPIO — PowerPlay summary: 453.88 mW total (415.34 static / 25.14 dynamic / 13.40 I/O).

Figure 12: MCU with GPIO and Interrupt Capability — PowerPlay summary: 455.09 mW total (415.35 static / 26.36 dynamic / 13.39 I/O).

## 4. Functional Verification and Waveform Analysis

Verification was carried out in two stages. First each peripheral was validated standalone against a dedicated test bench that drives the memory-mapped interface directly. Then the assembled MCU was simulated as a whole with tb_mcu, running the benchmark application from the ITCM while the internal signals of the CPU and of every peripheral instance were observed simultaneously.

### 4.1 Unit-level verification

GPIO. The test bench writes successive patterns to the port addresses 0x20–0x28 and reads them back. In the waveform, each MemWrite pulse latches TB_Data into the addressed register: 0xFF and 0xA5 appear on LEDR, and the values written to 0x22–0x27 appear on HEX0–HEX5 already encoded for the seven-segment displays (0x06 → HEX0 = 0x02, 0x5B → HEX1 = 0x47, and so on). The final transactions verify the read direction: with MemRead asserted the block drives 0x00000055 and 0x000000AA back onto DataBus, and the bus is released to high-impedance in every other cycle.

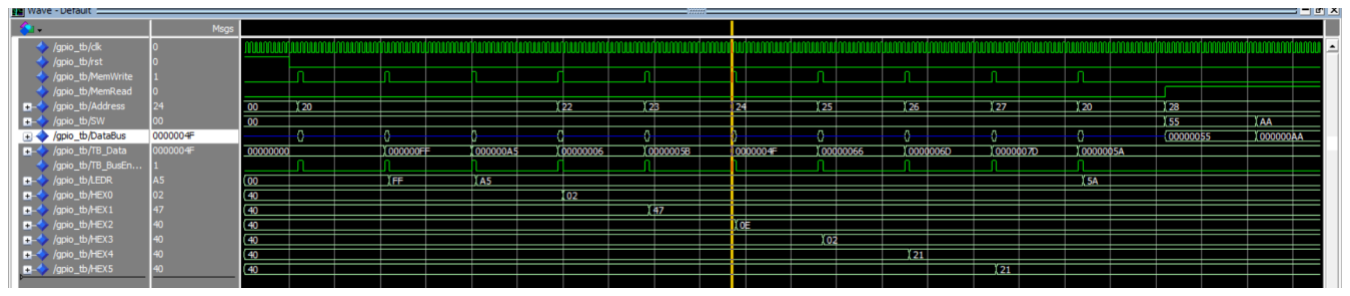
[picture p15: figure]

Figure 13: GPIO unit test bench — memory-mapped writes to LEDR and HEX0–HEX5 with SSD encoding, followed by read-back onto the tri-state DataBus.

Basic Timer. BTCTL1 is programmed with 0x20 (divider and mode select) and BTCMPR0 with 0x00000004. The internal divided clock clk_w toggles at half the rate of clk_q, and BTCNT_q counts 0 → 1 → 2 → 3 → 4 and then wraps to 0 exactly when it equals BTCMPR0, asserting EQU0_w for one divided-clock period. This confirms both the pre-scaler chain and the up-mode compare/clear behaviour that generates the periodic BTIFG interrupt.

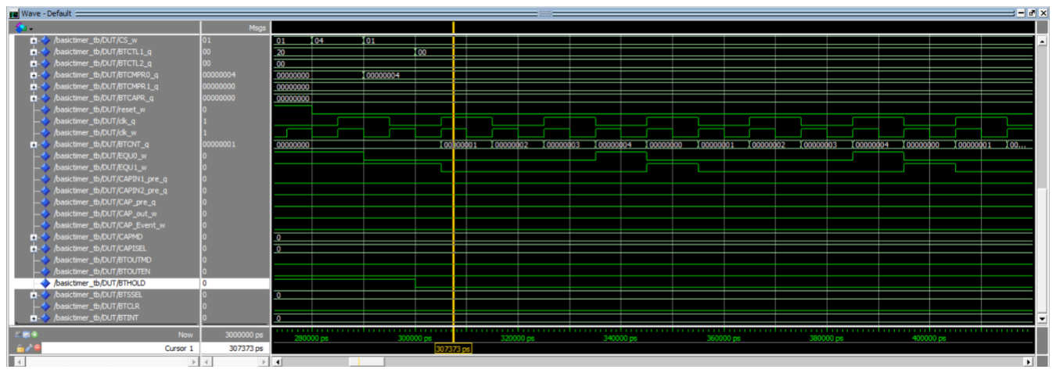
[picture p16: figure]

Figure 14: Basic Timer unit test bench — BTCNT_q counts to BTCMPR0 = 4 and reloads; EQU0_w pulses once per period.

Interrupt Controller. The controller is configured with IE = 0x7F (all sources enabled) and GIE = 1. Each request raises the corresponding bit of IFG (0x01, 0x02, 0x04, 0x08, 0x10, 0x20, 0x40 in turn) and asserts INTR_o; the CPU answers with INTA_i, at which point IR_q captures the pending source and Type_out_q presents the matching vector (0x08, 0x0C, 0x10, 0x14, 0x18, 0x1C, 0x04). The flag is then cleared and INTR_o is de-asserted, so the hand-shake completes correctly for every priority level and no request is lost or double-served.

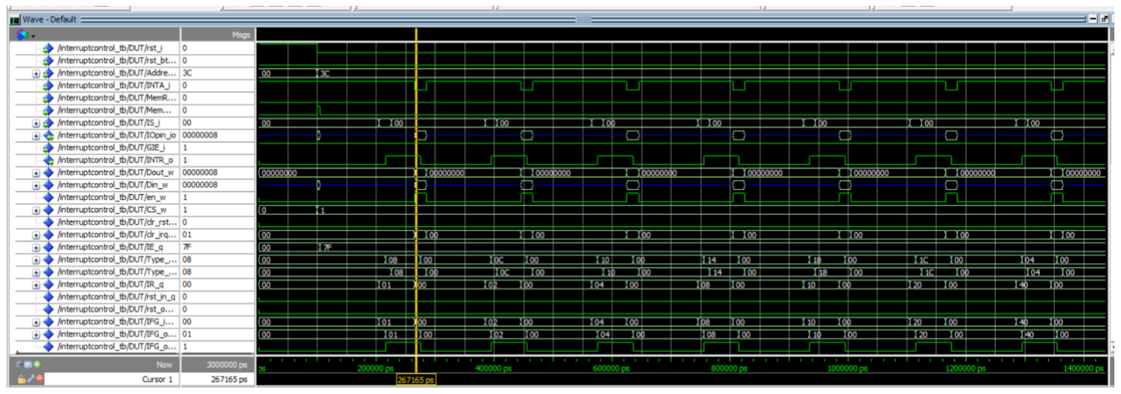
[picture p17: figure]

Figure 15: Interrupt Controller unit test bench — IFG/IR/Type_out sequence over seven consecutive requests with the INTR/INTA hand-shake.

### 4.2 System-level verification (tb_mcu)

With the peripherals proven, the structural MCU was simulated running the benchmark program. The top-level waveform shows the PC stepping through the program loop (0x1C → 0x20 → 0x24 → 0x28 → 0x2C → 0x3C → 0x40 → 0x50 → 0x54 → 0x64 and back) with the matching instruction words fetched from the ITCM, GIE_o and INTA_o asserted, and the HEX/LEDR outputs holding their programmed values. The reset push-buttons KEY0– KEY3 are released (logic 1) and SW = 0x3FF is presented to the GPIO.

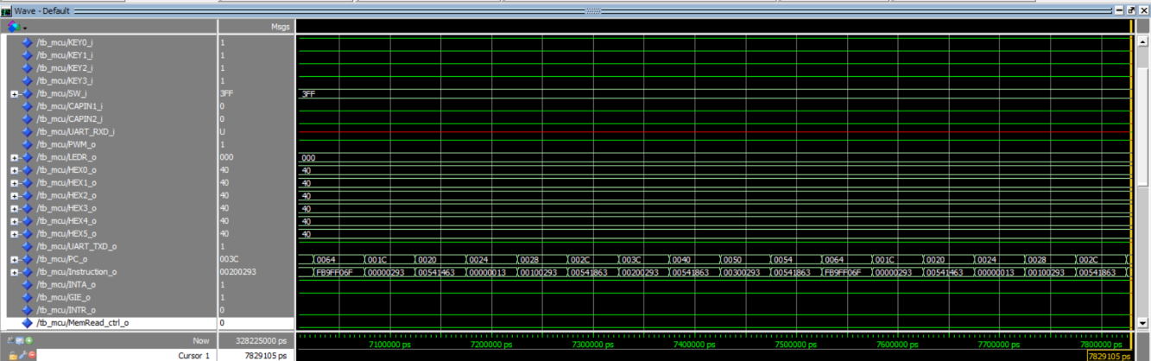
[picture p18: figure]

Figure 16: MCU top level — tb_mcu waveform showing the PC/instruction stream, the interrupt hand-shake signals and the board-level outputs.

The CPU view confirms the single-cycle behaviour inside the assembled system: one instruction retires per MCLK period, RegWrite_ctrl_o pulses on every arithmetic instruction, alu_res_o and write_data_o present the value in the same cycle in which dtcm_addr_o is driven, and the free-running mclk_cnt_o increments monotonically. Both clock domains (clk_i and divclk_i) are visible and running at their intended ratio.

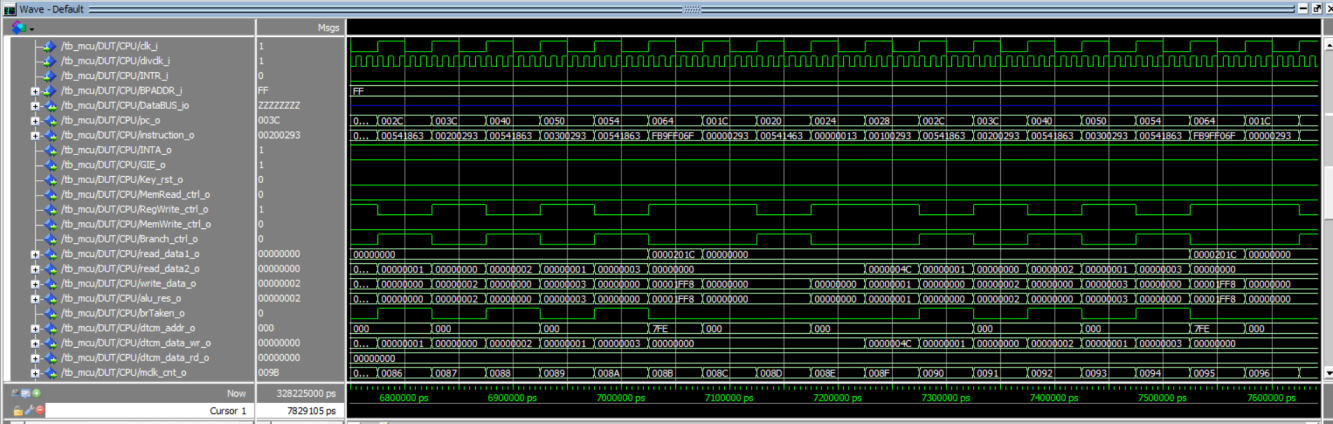
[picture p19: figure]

Figure 17: MCU — internal CPU signals (PC, instruction, control strobes, ALU/DTCM datapath and the MCLK counter) during the benchmark run.

The peripheral instances were observed at the same simulation time (cursor at 109.3 ns) so that the bus transactions can be correlated across blocks. In GPIO_UNIT the address bus walks through 0x1A, 0x20, 0x26,

0x27, 0x10, 0x1C with the corresponding chip-select values on CS_w, and the port registers keep their values while the bus is idle. In IC_UNIT the same accesses are decoded (IE_q = 0x3C, Type_out_q = 0x1C) and GIE_i toggles as the software enables and disables interrupts. In TIMER_UNIT the timer is programmed with BTCTL1 = 0x18 and BTCMPR0 = 0x002625A0, the divided clock clk_w runs at half of clk_q, BTCNT_q advances 0x84 → 0x85 → 0x86, and the capture path (CAPIN1_pre_q → CAP_pre_q → CAP_out_w) responds to the CAPIN stimulus.

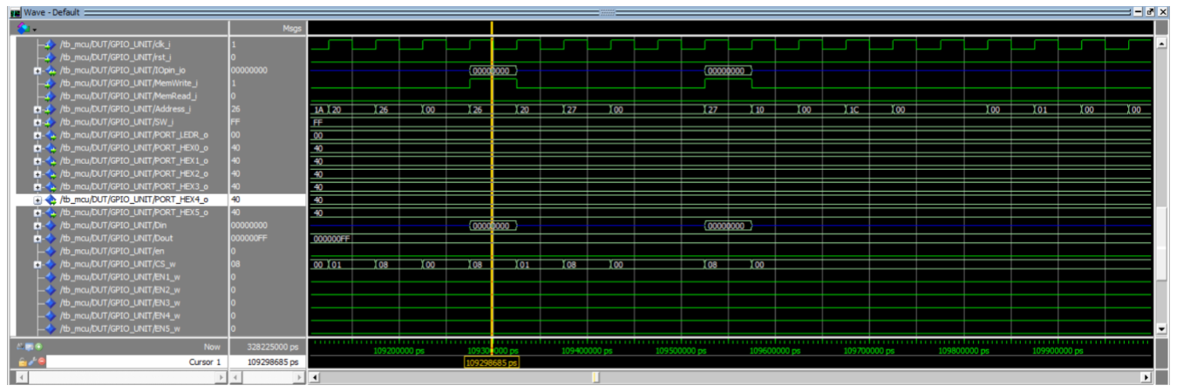
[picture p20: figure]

Figure 18: MCU — GPIO_UNIT instance: address decoding, chip-select generation and port registers during system operation.

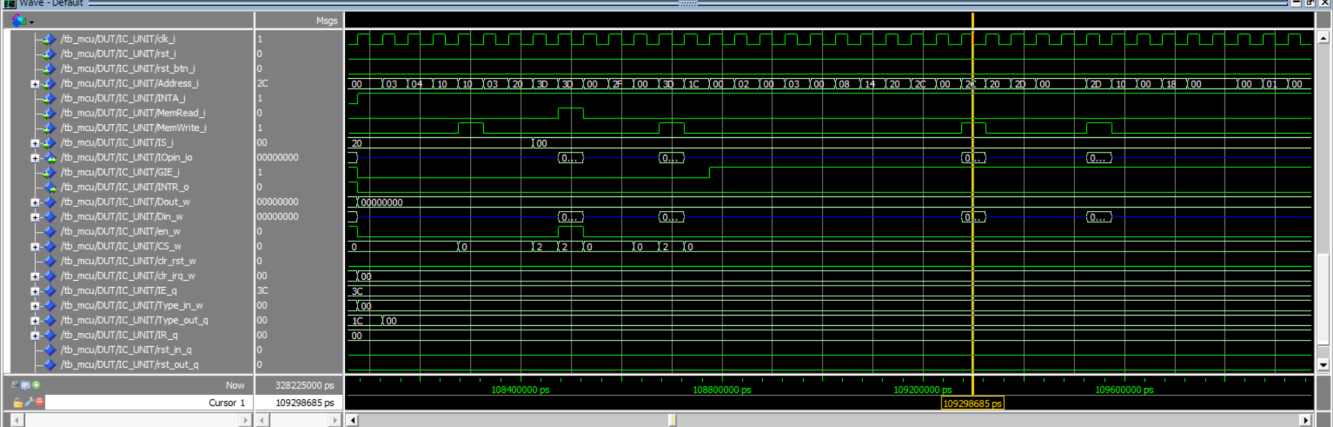
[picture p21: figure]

Figure 19: MCU — IC_UNIT instance: IE/Type registers and the INTR/INTA/GIE signalling seen from inside the assembled MCU.

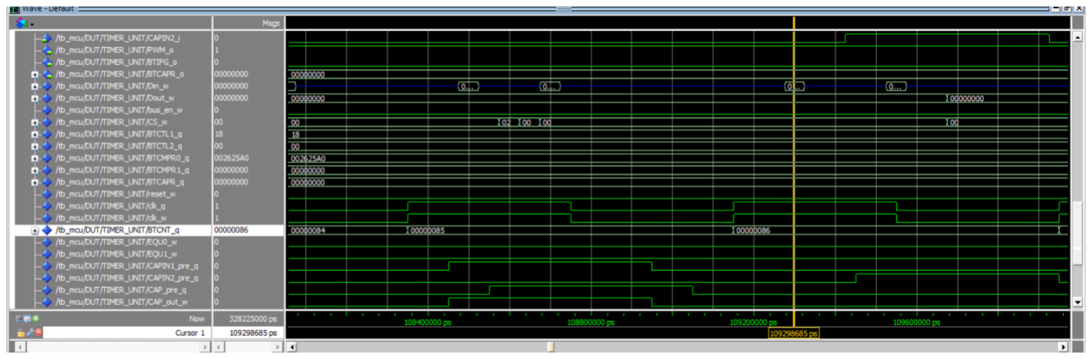
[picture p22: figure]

Figure 20: MCU — TIMER_UNIT instance: pre-scaled clock, BTCNT progression and the capture chain.

Taken together, the unit-level and system-level simulations show that every peripheral behaves identically inside the MCU as it did standalone, that the shared tri-state bus is driven by exactly one source at a time, and that the interrupt hand-shake operates correctly against the ISR FSM in the control unit.

### 4.3 On-board validation (Signal-Tap)

After the simulation flow the design was programmed onto the DE10-Standard board and the top-level ports were captured live with Signal-Tap, which closes the loop between the RTL model and the physical implementation. In the capture the program counter advances through the same instruction stream observed in ModelSim (0x00AC, 0x00B0, … 0x00CC, then the loop back through 0x0020, 0x0028, 0x002C, 0x003C, 0x0040,

0x0044, 0x0048) with the matching instruction words, and the free-running MCLK counter increments monotonically (0xF54E → 0xF55D), confirming that the core runs from the PLL-generated MCLK without stalling.

The peripheral outputs are captured on the same trigger: HEX0 = 0x78 and HEX1 = 0x02 hold the values written by the benchmark through the GPIO port registers, HEX2–HEX5 remain at their reset pattern 0x40, LEDR is cleared, PWM_o is low in the captured window and UART_TXD idles high as expected for an idle line. The reset net rst_w is de-asserted and KEY0–KEY3 read as released, so the capture represents normal operation rather than a reset condition. These values match the ModelSim run of the same benchmark, which confirms that the MCU behaves identically in simulation and on the board.

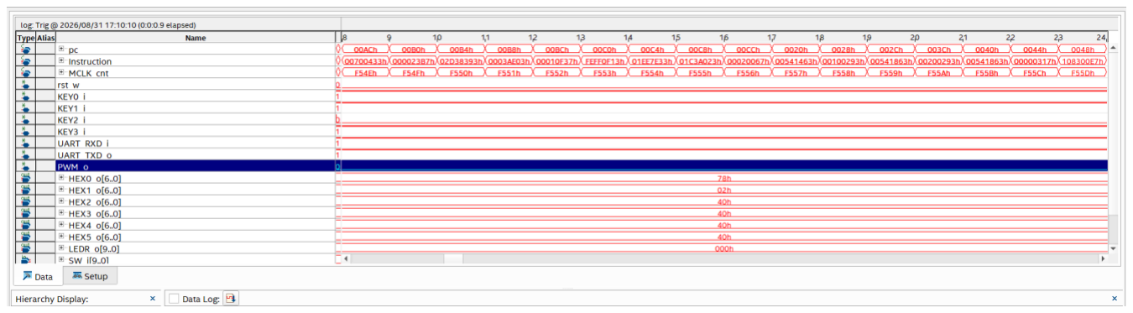
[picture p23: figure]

Figure 21: On-board Signal-Tap capture of the MCU top-level ports — PC and instruction stream, MCLK counter, push-buttons, UART lines, PWM and the HEX / LEDR outputs.

## 5. Conclusions

A complete structural RV32IM micro-controller was implemented on the DE10-Standard board, combining the single-cycle core of LAB5 with a memory-mapped peripheral subsystem (GPIO with SSD decoders, Basic Timer with PWM and capture, Interrupt Controller, UART and a restoring-divider accelerator on a separate clock domain).

The PPA comparison between the two implemented configurations shows that interrupt capability, serial communication and the division accelerator are inexpensive in area (+6.0 % ALMs, +2.3 % registers, with identical memory, DSP and PLL usage) and almost free in power (+1.21 mW total, entirely in the dynamic term). They are also effectively free in clock frequency: 28.37 MHz with GPIO alone against 29.09 MHz with the full peripheral set, a 2.5 % spread that reflects fitter variation rather than an architectural difference. The real performance cost is the step from a bare CPU to a micro-controller: 29.09 MHz against 34.99 MHz for the LAB5 core. The technology-map analysis locates the worst-case path in the IDECODE register-file read multiplexer chain, running from the ITCM output to the operand register of the divider synchroniser, so the added fan-out of the register-file read — not the peripheral bus itself — is what limits the clock. The divider datapath, in its own 139.55 MHz DIVCLK domain, is comfortably clear. The system is operated at f_MCLK = f_sysclk = 25 MHz, inside the worst-case Fmax of both configurations.

Functional correctness was established bottom-up: each peripheral was verified standalone against its own test bench, then re-verified in place inside the assembled MCU running the benchmark program, and finally confirmed on the board with Signal-Tap, which reproduced the same PC / instruction stream and the same peripheral outputs as the RTL simulation.

Remaining work. The GPIO-only Fmax report and the full PPA set for the pipelined configuration still have to be captured; once available they complete the three rows of Tables 1–3 and allow the same single-cycle-versus-pipelined trade-off analysis performed in LAB5 to be repeated at MCU level.

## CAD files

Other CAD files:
QUARTUS/stp1.stp

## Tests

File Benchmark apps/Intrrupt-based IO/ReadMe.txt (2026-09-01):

=======================================================================================
					Description of the application test1:
=======================================================================================
Input:  KEY3, KEY2, KEY1, SW0
Output: PORT_HEX0,PORT_HEX1,PORT_HEX2,PORT_HEX3,PORT_HEX4,PORT_HEX5,PORT_LEDR
RESET:  KEY0
----------------------------------------------------------------------------------------
On RESET:
--------
*)clear (turn off) the six HEXs and red LEDRs[7-0]
*)set the value of delay cycles of the delay routine (SW0=0: short delay, SW0=1: long delay)   

On KEY1 pushing:
---------------
The FSM's state1 is chosen:
*)print onto HEX5,HEX4 the value of arr1[i]
*)goto idle state 

On KEY2 pushing:
---------------
The FSM's state2 is chosen:
*)print onto HEX3,HEX2 the value of arr2[i]
*)goto idle state 

On KEY3 pushing:
---------------
The FSM's state3 is chosen(periodic of SIZE):
*)print onto HEX5,HEX4 the value of arr1[i]
*)print onto HEX3,HEX2 the value of arr2[i]
*)print onto HEX1,HEX0 the qoutient value of arr1[i]/arr2[i]
*)print onto LEDRs[7-0] the reminder value of arr1[i]%arr2[i]
*)i=(i<SIZE)?i+1 :0
*)delay
*)if(i==SIZE) goto idle state  
========================================================================================
					Description of the source code test2:
========================================================================================
Input:  KEY3, KEY2, KEY1
Output: PORT_HEX0,PORT_HEX1,PORT_HEX2,PORT_HEX3,PORT_HEX4,PORT_HEX5,PORT_LEDR
RESET:  KEY0
----------------------------------------------------------------------------------------
On RESET:
--------
The FSM's state0 is chosen

On KEY1 pushing:
---------------
The FSM's state1 is chosen:
*)print onto HEX1,HEX0 the value of a0
*)goto idle state 

On KEY2 pushing:
---------------
The FSM's state2 is chosen:
*)print onto HEX3,HEX2 the value of a0
*)goto idle state   

On KEY3 pushing:
---------------
The FSM's state3 is chosen:
*)print onto HEX5,HEX4 the value of a0
*)goto idle state 

On every BT interrupt-interval of 1sec (value of 0x002625A0 is for SMCLK=20MHz):
-------------------------------------------------------------------------------
a0=a0+1

Notes:
*)the BT timer source clock is SMCLK/8
*)SMCLK=20MHz is only an example:
	Your SMCLK should be MCLK=SMCLK or MCLK=k*SMCLK (k is an integer) depends the design critical-path constraint,
	when the application behavior accordingly 
========================================================================================
					Description of the source code test3:
========================================================================================
Input:  KEY3, KEY2, KEY1
Output: PORT_HEX0,PORT_HEX1,PORT_HEX2,PORT_HEX3,PORT_HEX4,PORT_HEX5,PORT_LEDR
RESET:  KEY0
----------------------------------------------------------------------------------------
On RESET:
--------
*)Set the interrupt-interval to 1sec(BTCMPR0=0x002625A0, timer_source = SMCLK/8, SMCLK=20MHz)
*)The FSM's state0 is chosen 

On KEY1 pushing:
---------------
*)Set the interrupt-interval to 0.5sec(BTCMPR0=0x002625A0/2, timer_source = SMCLK/8, SMCLK=20MHz)
*)The FSM's state1 is chosen:
	print onto HEX1,HEX0 the value of a0
	print onto LEDRs[7-0] the value of a0
*)goto idle state 

On KEY2 pushing:
---------------
*)Set the interrupt-interval to 0.25sec(BTCMPR0=0x002625A0/4, timer_source = SMCLK/8, SMCLK=20MHz)
*)The FSM's state2 is chosen:
	print onto HEX3,HEX2 the value of a0
	print onto LEDRs[7-0] the value of a0
*)goto idle state 

On KEY3 pushing:
---------------
*)Set the interrupt-interval to 0.125sec(BTCMPR0=0x002625A0/8, timer_source = SMCLK/8, SMCLK=20MHz)
*)The FSM's state3 is chosen:
	print onto HEX5,HEX4 the value of a0
	print onto LEDRs[7-0] the value of a0
*)goto idle state 

On every BT interrupt-interval:
------------------------------
a0=a0+1

Note:
*)SMCLK=20MHz is only an example:
	Your SMCLK should be MCLK=SMCLK or MCLK=k*SMCLK (k is an integer) depends the design critical-path constraint,
	when the application behavior accordingly
=====================================================================================
										Description of the source code test4:
=====================================================================================
Input:  KEY3, KEY2, KEY1
Output: PORT_HEX0,PORT_HEX1,PORT_HEX2,PORT_HEX3,PORT_HEX4,PORT_HEX5,PORT_LEDR,PWM_PIN
RESET:  KEY0
--------------------------------------------------------------------------------------
On RESET:
--------
clear all HEXs

On KEY1 pushing:
---------------
*)The BT timer is configured to compare mode
*)The interrupt interval is updated in a row for each KEY1 pushing from values 1sec,0.5sec,0.25sec,0.125sec  
*)For every interval value: a0=a0+1; print onto HEXsArr the value of a0
*)goto idle state 

On KEY2 pushing:
---------------
*)The BT timer is configured to output compare mode, PWM output signal=5kHZ
*)The PWM output signal duty-cycle is updated in a row for each KEY2 pushing from values 50%,75%,87.5%,93.75%
*)goto idle state 

On KEY3 pushing:
---------------
*)The BT timer is configured to input capture mode
*)Time measurement of a function:
	- On even KEY3 pushing:
		The application measures the runtime of two arrays division element by element
	-	On odd KEY3 pushing:
		The application measures the runtime of two arrays modulu element by element
*)goto idle state

Note:
*)SMCLK=20MHz is only an example:
	Your SMCLK should be MCLK=SMCLK or MCLK=k*SMCLK (k is an integer) depends the design critical-path constraint,
	when the application behavior accordingly
